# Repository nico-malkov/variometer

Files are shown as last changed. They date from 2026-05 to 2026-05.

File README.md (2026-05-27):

<b> Variometer v1.5 (hardware) v143 (software) </b>

The goal of this project is to create a miniature smart device for hobby paragliding: a variometer. The initial concept is as follows:

 <br>

<b> The current version of the project has successfully achieved its technical objectives and is being released for public access. It implements the following features: </b>

• Compact size and minimum weight of 23 grams <br>
• Power from solar cells of 170 mW at peak with consumption of 40 mW at average <br>
• IP67 rating with PTFE vented barometer membrane <br>
• Acoustic variometer with responsive Kalman filter, combining data from ms5637 barometer and icm20948 IMU <br>
• Built-in capacitive touch button <br>
• nRF52840 Cortex-M4 microcontroller unit with Bluetooth capability <br>
• Secure firmware update via Bluetooth with NRF Connect android app <br>
• Integration with XCTrack android app for sourcing barometer data <br>
• Sourcing of GPS data from ORG1410 module <br>
• Creation of txt logs <br>
• Connection to PC via USB as a mass-storage device <br>



 <br>

<b> The flaws of the current design include: </b>

• No IGC-format GPS tracking in software (to-do) <br>
• Large power consumption in GPS tracking mode: up to 60 mW <br>
• Custom manufacturing of solar cells is totally unpractical even though it is possible <br>

 <br>

<b> The project folder contains 'hardware' and 'software' subfolders: </b> <br>

1) The 'hardware' folder contains a "PCB" subfolder with the complete project in Altium Designer. To open it start with the file: <br>
variometer\hardware\PCB\v1.5 Project.PrjPcb <br>

 <br>

2) The 'hardware' folder contains a 'case' subfolder with the 3D model in Solid Works. To open it start with the file: <br>
variometer\hardware\case\v1.5 Case.SLDPRT <br>

 <br>

3) The 'software' folder contains an 'nRF5_SDK_17.1.0' subfolder with the complete project in Segger Embedded Studio. To open it start with the file: <br>
variometer\software\nRF5_SDK_17.1.0\examples\peripheral\variometer_v143\vario1d5\s140\ses\vario1d5_s140.emProject <br>

 <br>

Please contact me with any questions via email nicomalkov@yandex.com <br>

<b> Cheers! </b> <br>



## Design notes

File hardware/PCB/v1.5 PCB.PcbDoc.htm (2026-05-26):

Reporting Options

# File in Newer Format

Date | : | 15.07.2021
Time | : | 13:31:14
Filename | : | C:\Users\Engineer\YandexDisk-nicomalkov\Share\Altium\Ungravity 1.5\Ungravity 1.5 PCB.PcbDoc

Version | Warning
Release 17.0 | CAUTION - Component parameters added.
Release 17.0 | CAUTION - Supports of backdrilling

This file was generated by a later version of the software

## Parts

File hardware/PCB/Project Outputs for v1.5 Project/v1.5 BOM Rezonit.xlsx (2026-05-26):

Comment | Description | Designator | Footprint | LibRef | Quantity
10 uF |  | C1, C7, C9, C22 | 0603 | Capasistor | 4
0.01 uF |  | C2, C4 | 0402 | Capasistor | 2
4.7 uF |  | C3, C6, C8, C11, C14 | 0402 | Capasistor | 5
0.1 uF |  | C5, C10, C15, C16, C18, C19, C20, C21, C23 | 0402 | Capasistor | 9
8 pF |  | C12, C13 | 0402 | Capasistor | 2
Do not assemble (else - 8 pF) |  | C17 | 0402 | Capasistor | 1
BAS16XV2T1G |  | D1 | SOD-523 | Diode | 1
Comment |  | Designator3, Designator4, Designator5, Designator6, Designator7, Designator8 | FIDUCIAL MARK |  | 6
LiPo 150 mA*h |  | G1 | LPV551230 | Accumulator | 1
IFSC1515AHER220M01 22 uH |  | L1 | IFSC1515-AH-01 | Inductor | 1
IFSC1515AHER2R2M01 2.2 uH |  | L2 | IFSC1515-AH-01 | Inductor | 1
Test сonnector pads |  | P1 | TEST CONNECTOR | Test сonnector pads | 1
U-E-M5SS-W-0 |  | P2 | U-E-M5SS-W-0 | micro-USB port | 1
SMAT-13S |  | PZT1 | SMAT-13-MOUNT BY WIRE | Piezo transducer | 1
250 R |  | R1 | 0402 | Resistor | 1
3.9 M |  | R2, R10, R11, R17 | 0402 | Resistor | 4
5.49 M |  | R3, R9 | 0402 | Resistor | 2
3.65 M |  | R4 | 0402 | Resistor | 1
6 M |  | R5 | 0402 | Resistor | 1
1 M |  | R6 | 0402 | Resistor | 1
10 M |  | R7 | 0402 | Resistor | 1
4.87 M |  | R8 | 0402 | Resistor | 1
500 R |  | R12, R18 | 0402 | Resistor | 2
6.6 K |  | R13, R14, R15, R19, R20, R21, R24 | 0402 | Resistor | 7
5.76 M |  | R16 | 0402 | Resistor | 1
27 R |  | R22, R23 | 0402 | Resistor | 2
B3U-1000P |  | SW1 | B3U-1000P | Tact switch | 1
BQ25504 |  | U1 | BQ25504 | BQ25504 | 1
TPS62740DSSR |  | U2 | TPS62740 | TPS62740 | 1
MCP73832-2ATI/MC |  | U3 | MCP73832-2ATI/MC | MCP73832-2ATI/MC | 1
MDBT50Q-P1MV2 (NRF52840) |  | U4 | MDBT50Q-P1M | MDBT50Q | 1
TLV9002SIRUGR |  | U5 | X2QFN | TLV9002S | 1
MX25R6435FZAIL0 |  | U6 | MX25R6435F-ZA | MX25R6435F-ZA | 1
TTP223-BA6 |  | U7 | SOT23-6 | TTP223-BA6 | 1
ICM20948 |  | U8 | ICM20948 | ICM20948 | 1
MS5637 |  | U9 | MS5637-02BA03 | MS5637-02BA03 | 1
ORG1410-PM01 |  | U10 | ORG1410-PM01 | ORG1410-PM01 | 1
PESD5Z5.0 |  | VD1, VD2, VD3, VD4 | SOD-523 | Stabilitron | 4
PESD5Z7.0 |  | VD5 | SOD-523 | Stabilitron | 1
9HT11-32.768KDZY-T |  | XC1 | 9HT11 | Qartz | 1

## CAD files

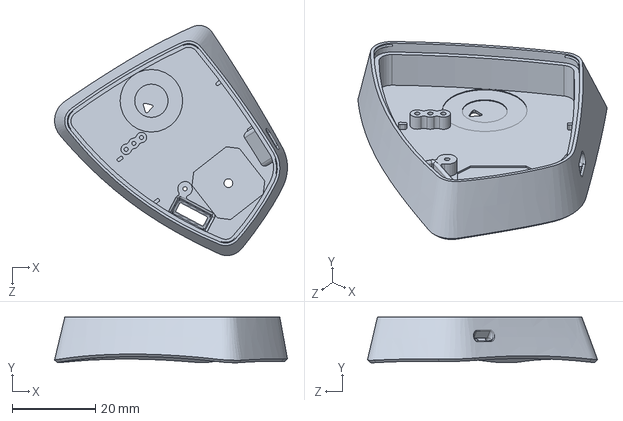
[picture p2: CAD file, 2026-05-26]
hardware/case/v1.5 Case.SLDPRT
55.8 x 10.9 x 55.2 mm

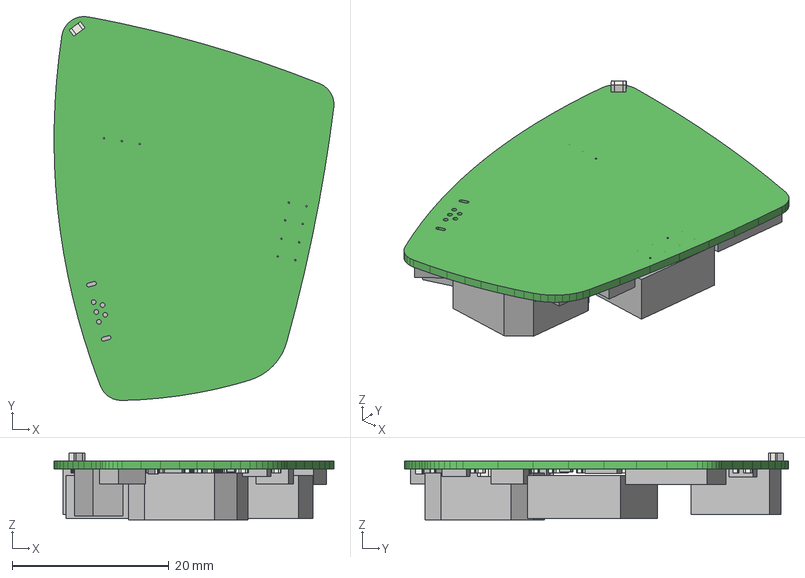
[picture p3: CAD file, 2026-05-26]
hardware/PCB/v1.5 PCB.step
35.7 x 48.9 x 8.50 mm
Board
Extruded x 173

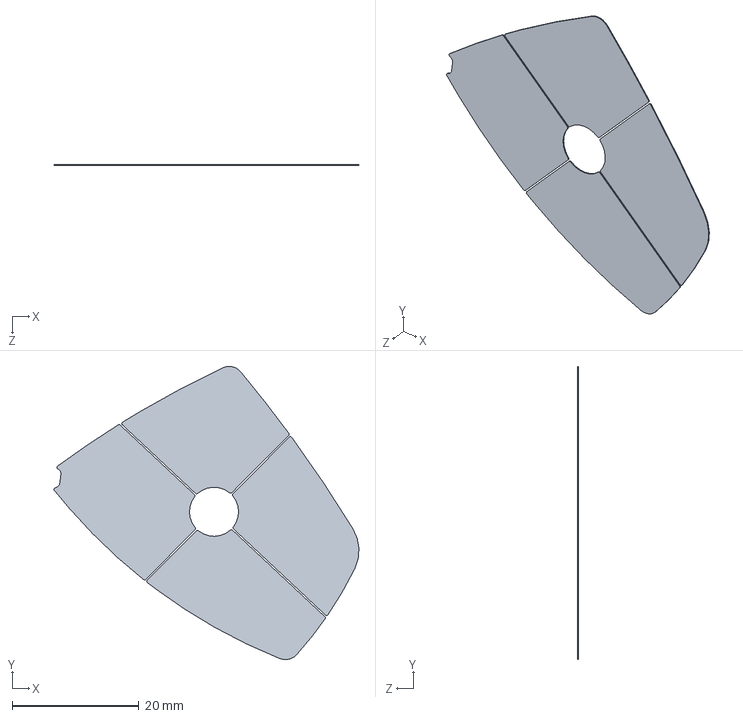
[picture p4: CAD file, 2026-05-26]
hardware/case/Solar Cells.SLDPRT
48.1 x 46.3 x 0.16 mm

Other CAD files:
hardware/case/v1.5 Case.STL

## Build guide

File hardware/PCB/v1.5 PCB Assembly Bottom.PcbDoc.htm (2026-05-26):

Reporting Options

# File in Newer Format

Date | : | 28.06.2021
Time | : | 20:50:02
Filename | : | C:\Users\Engineer\YandexDisk-nicomalkov\Share\Altium\Ungravity 1.5\Ungravity 1.5 PCB Assembly Bottom.PcbDoc

Version | Warning
Release 17.0 | CAUTION - Component parameters added.
Release 17.0 | CAUTION - Supports of backdrilling

This file was generated by a later version of the software

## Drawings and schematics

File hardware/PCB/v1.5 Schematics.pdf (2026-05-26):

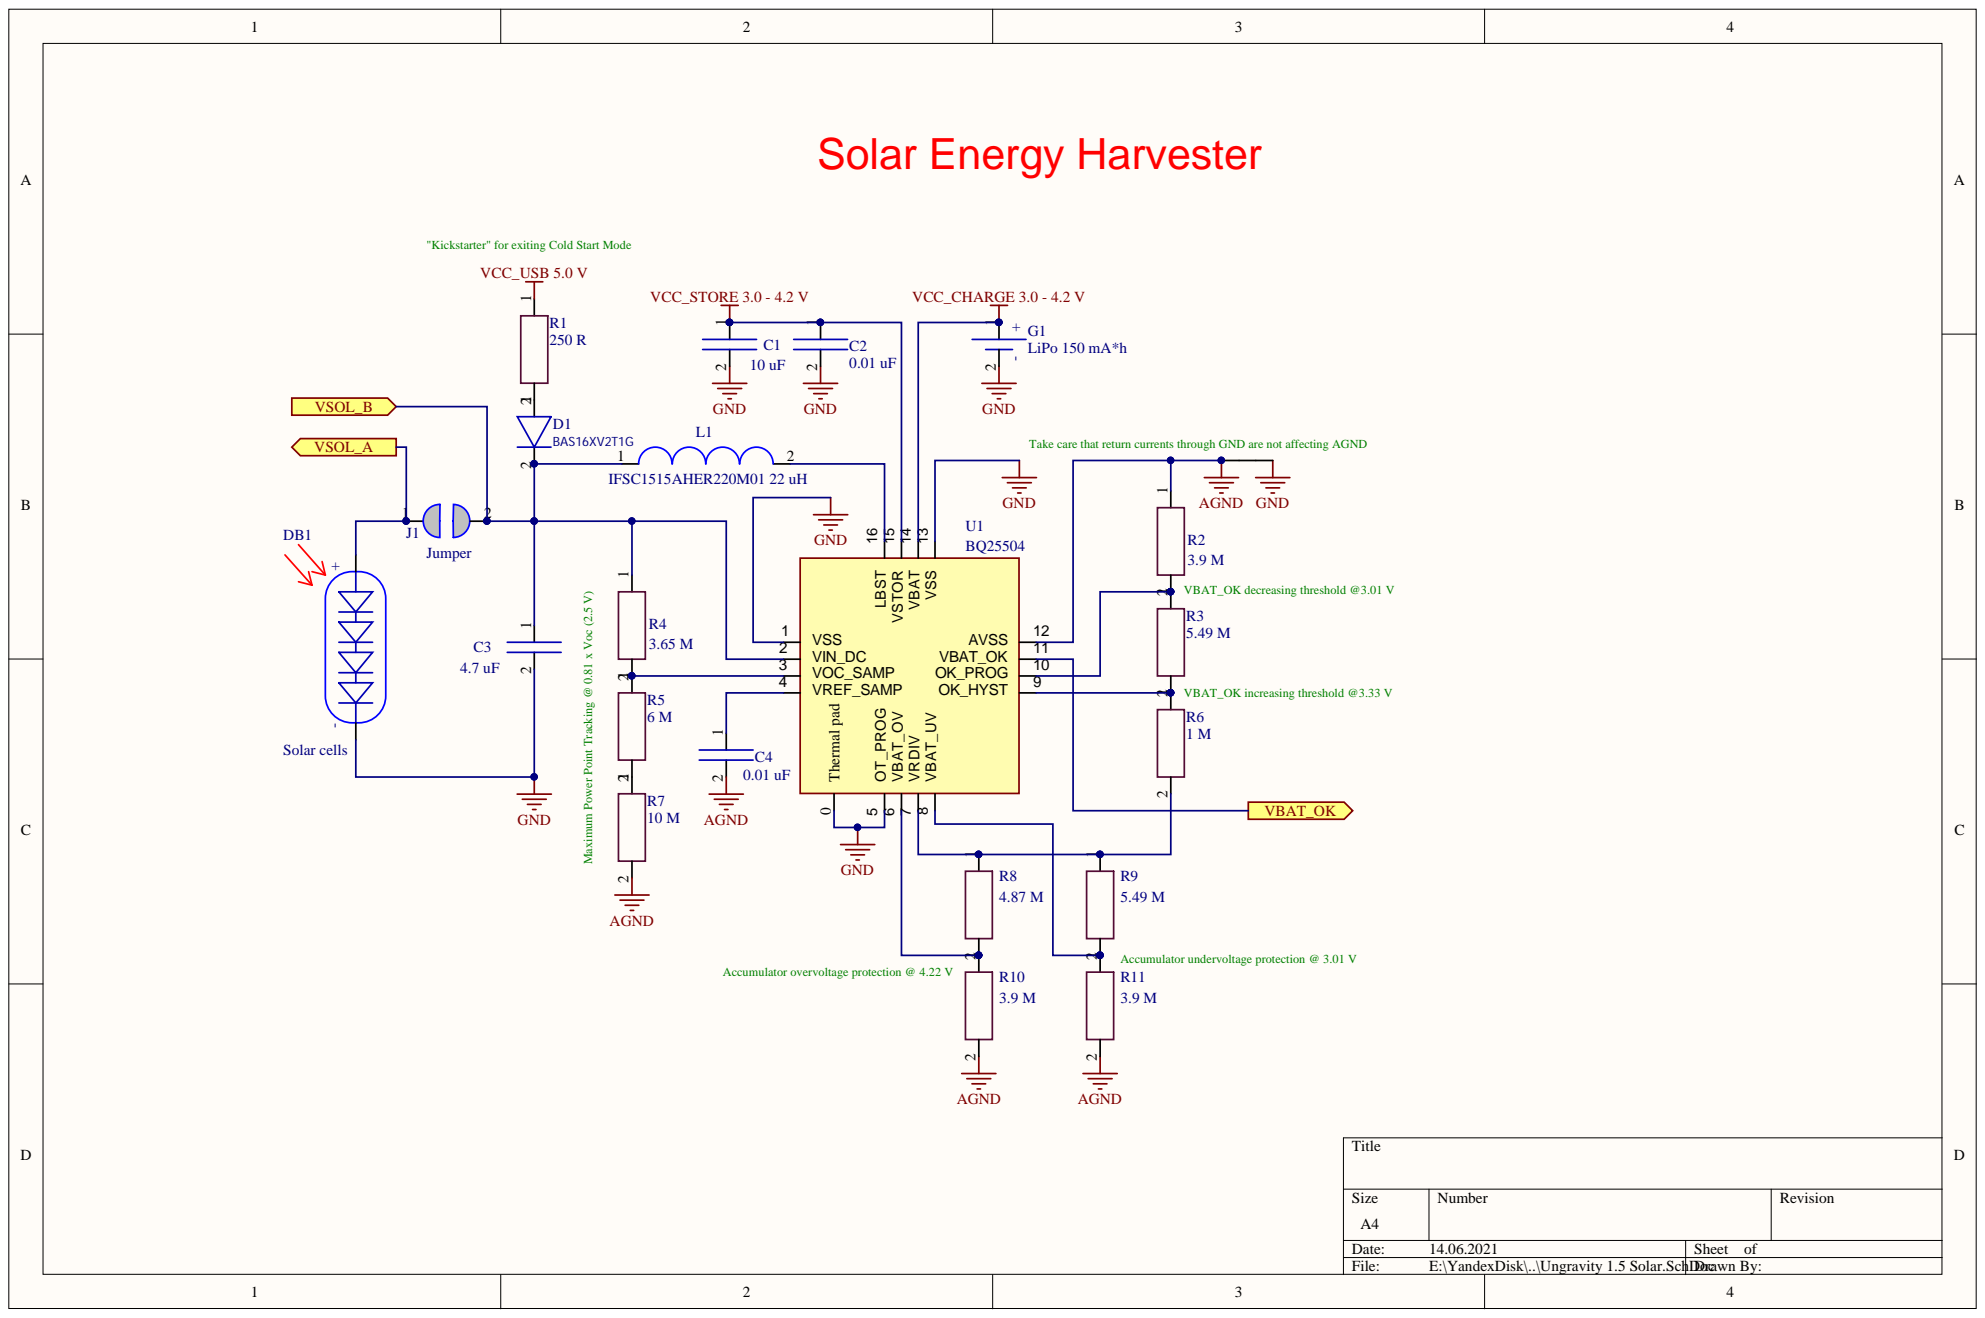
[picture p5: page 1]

Take care that return currents thro

VSS 13 VBAT 14 VSTOR 15 LBST 16

Maximum Power Point Tracking @ 0.81 x Voc (2.5 V)

2 | V I N V O V | 1 1
3 | | 1 0

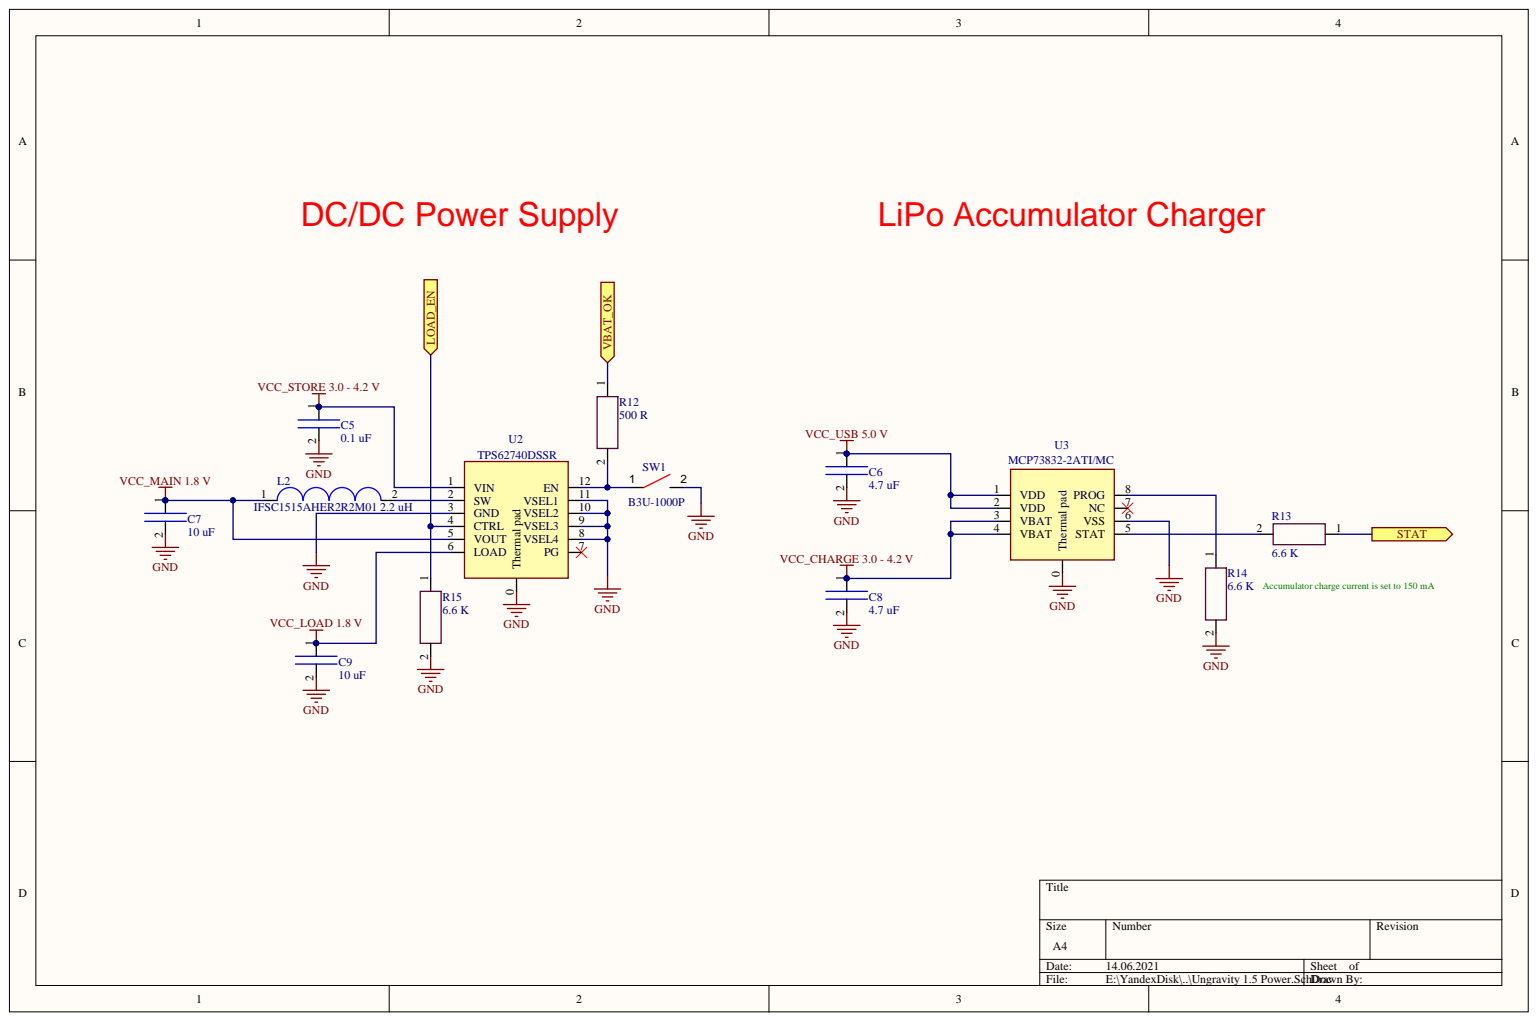
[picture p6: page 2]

ulator charge current is set to 1

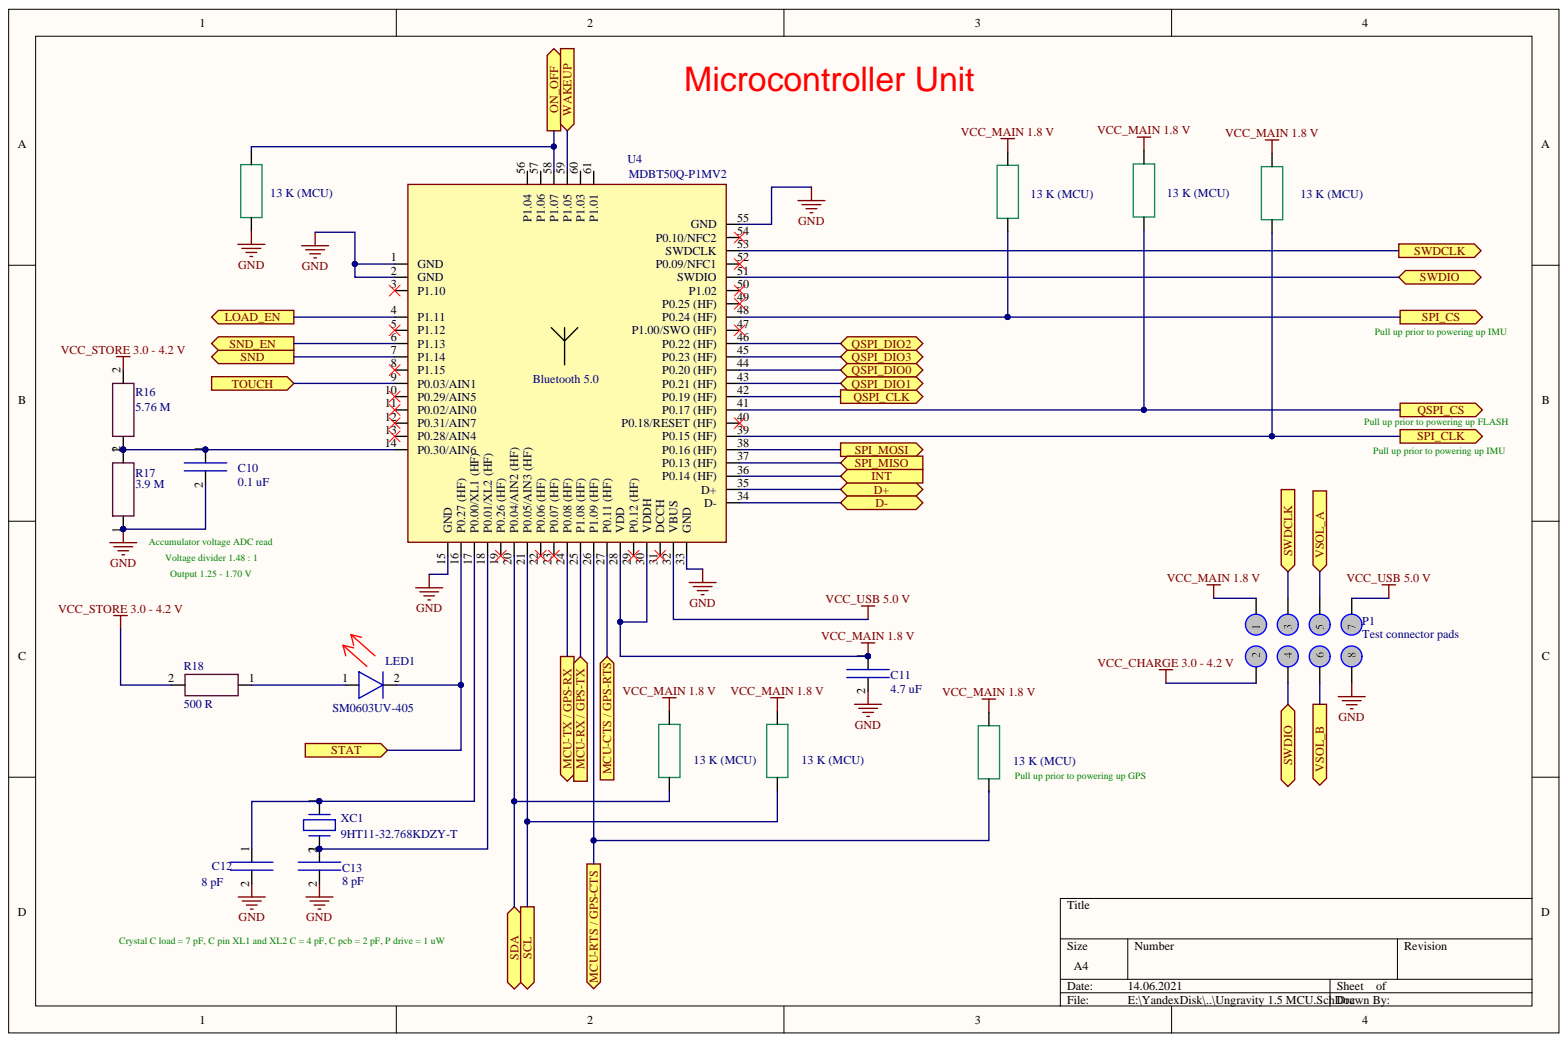
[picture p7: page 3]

Crystal C load = 7 pF, C pin XL

2 C = 4 pF, C pcb = 2 pF, P drive = 1 u

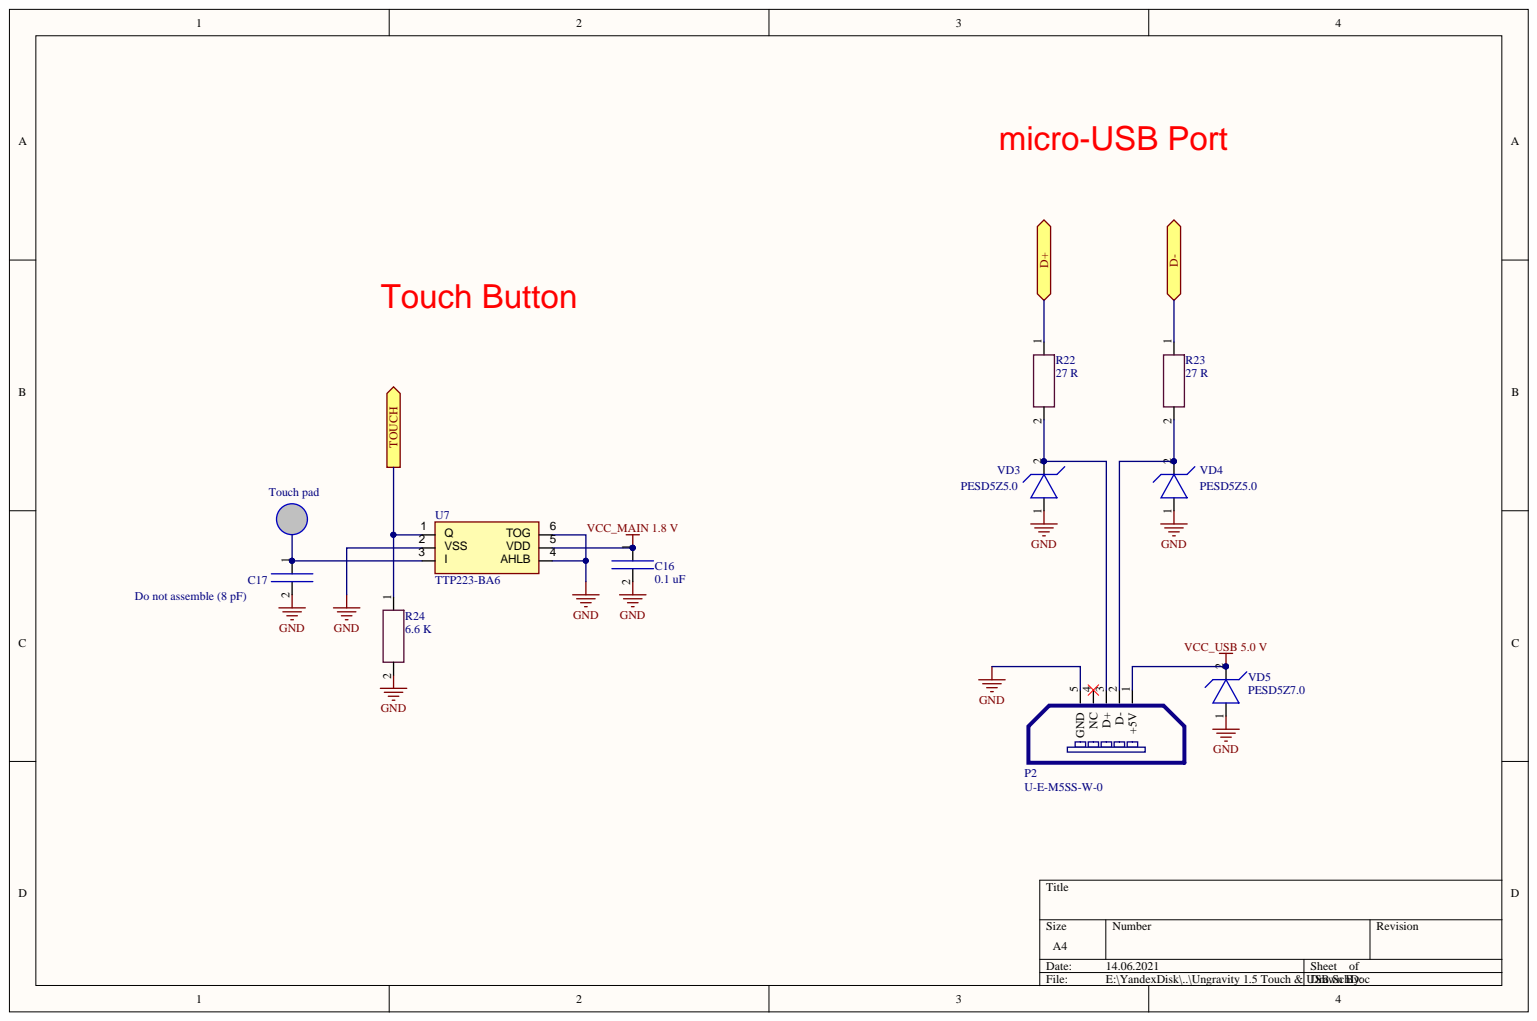
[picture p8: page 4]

Do not assemble (8 pF)

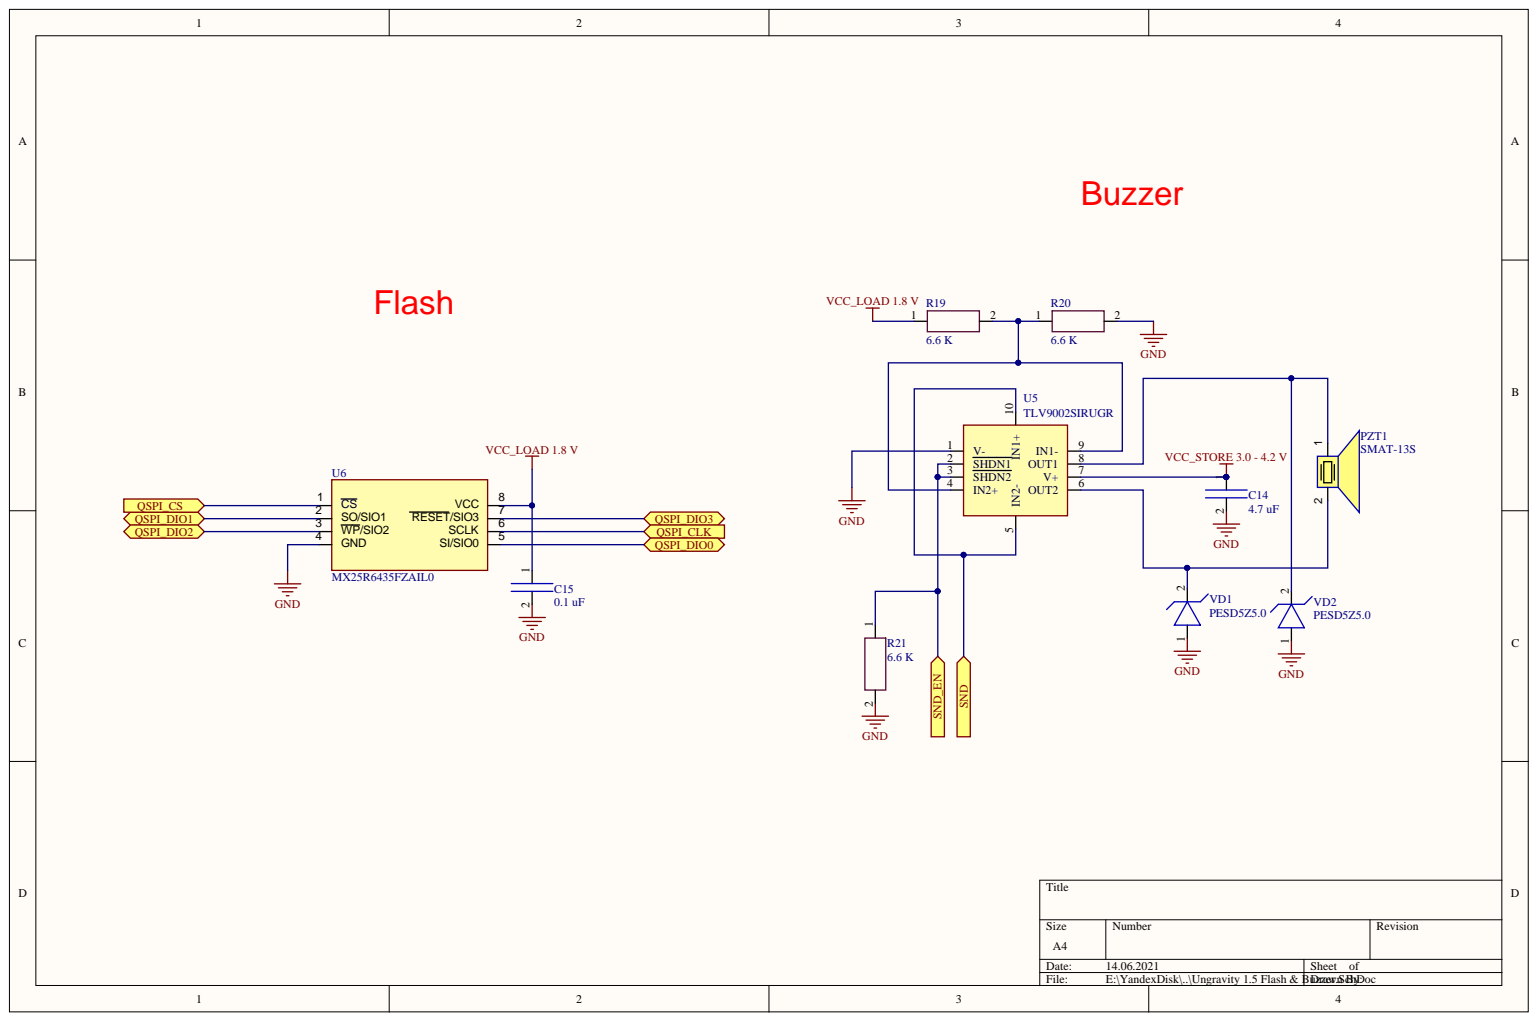
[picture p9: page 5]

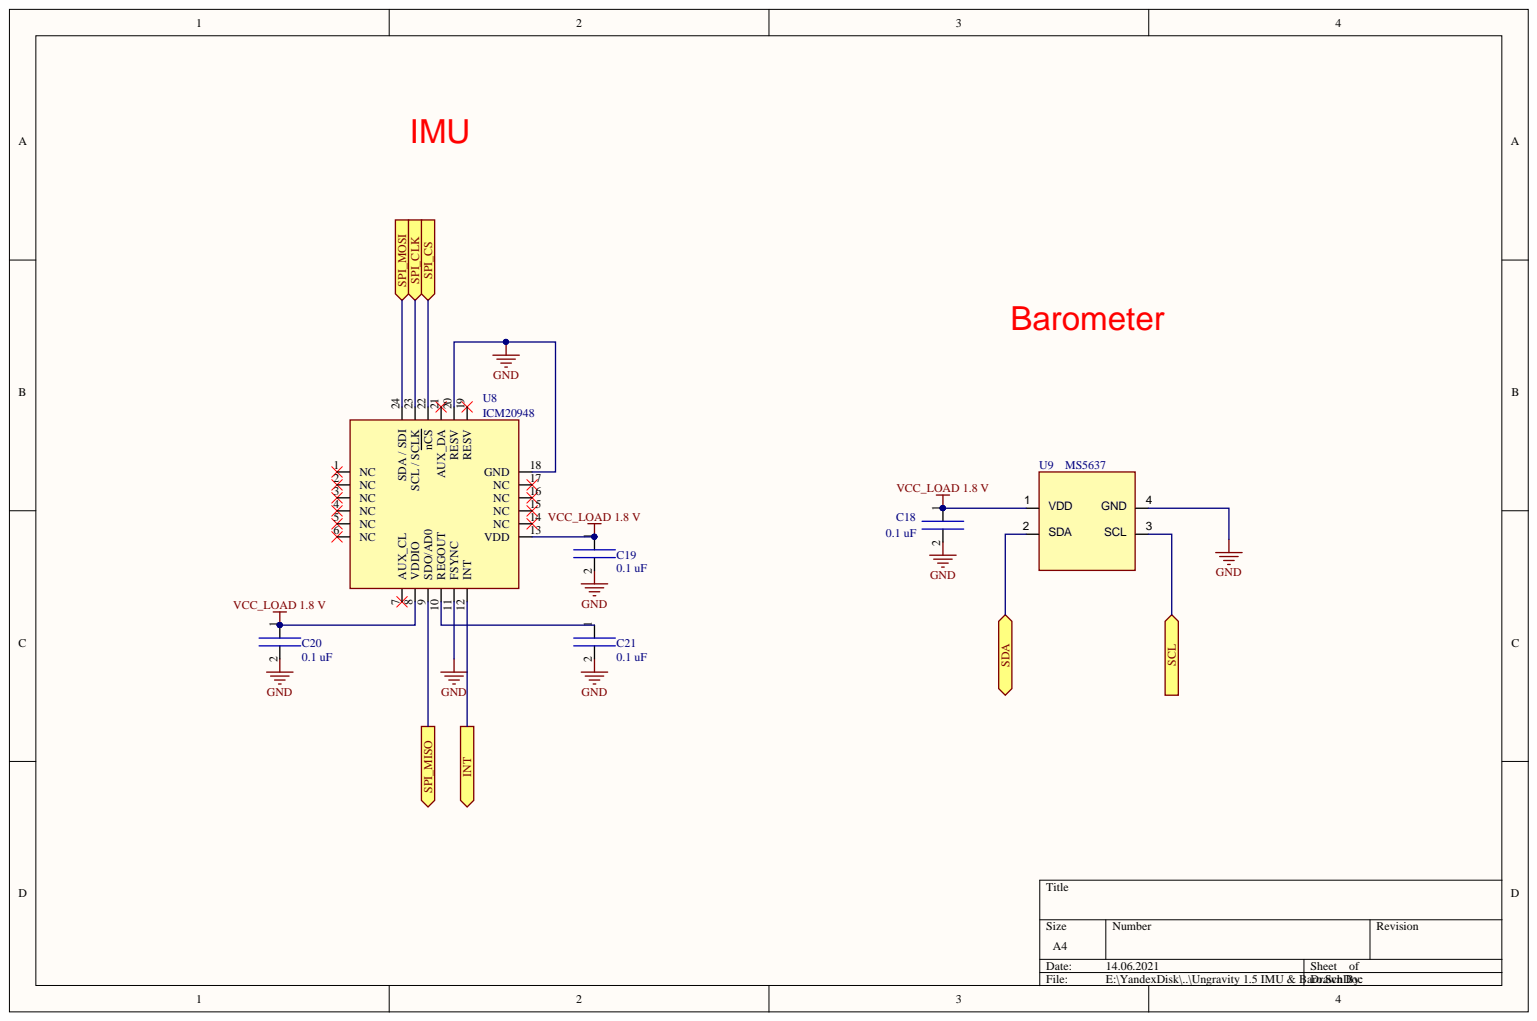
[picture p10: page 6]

RESV 19 RESV 20 AUX_DA 21 nCS 22 SCL / SCLK 23 SDA / SDI 24

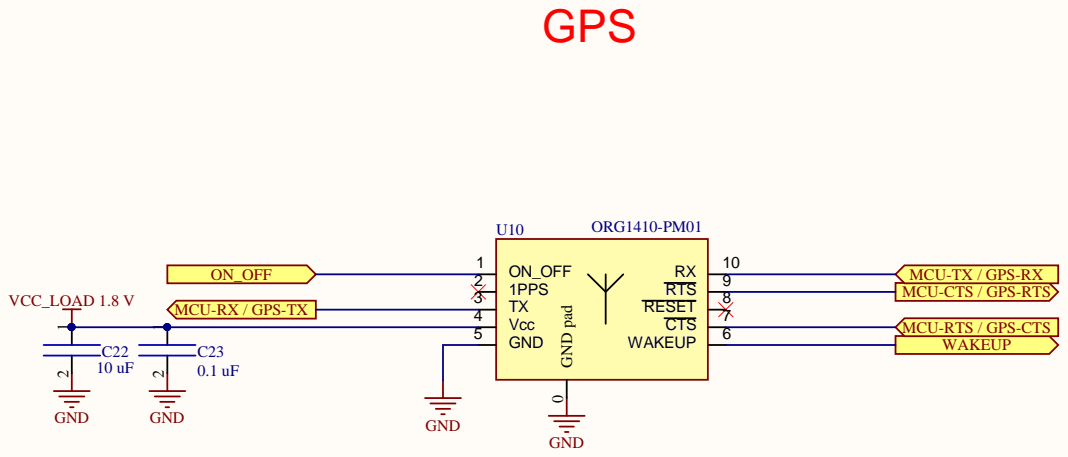
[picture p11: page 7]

MCU-TX / GPS-RX
MCU-CTS / GPS-RTS

MCU-RX / GPS-TX

MCU-RTS / GPS-CTS
WAKEUP

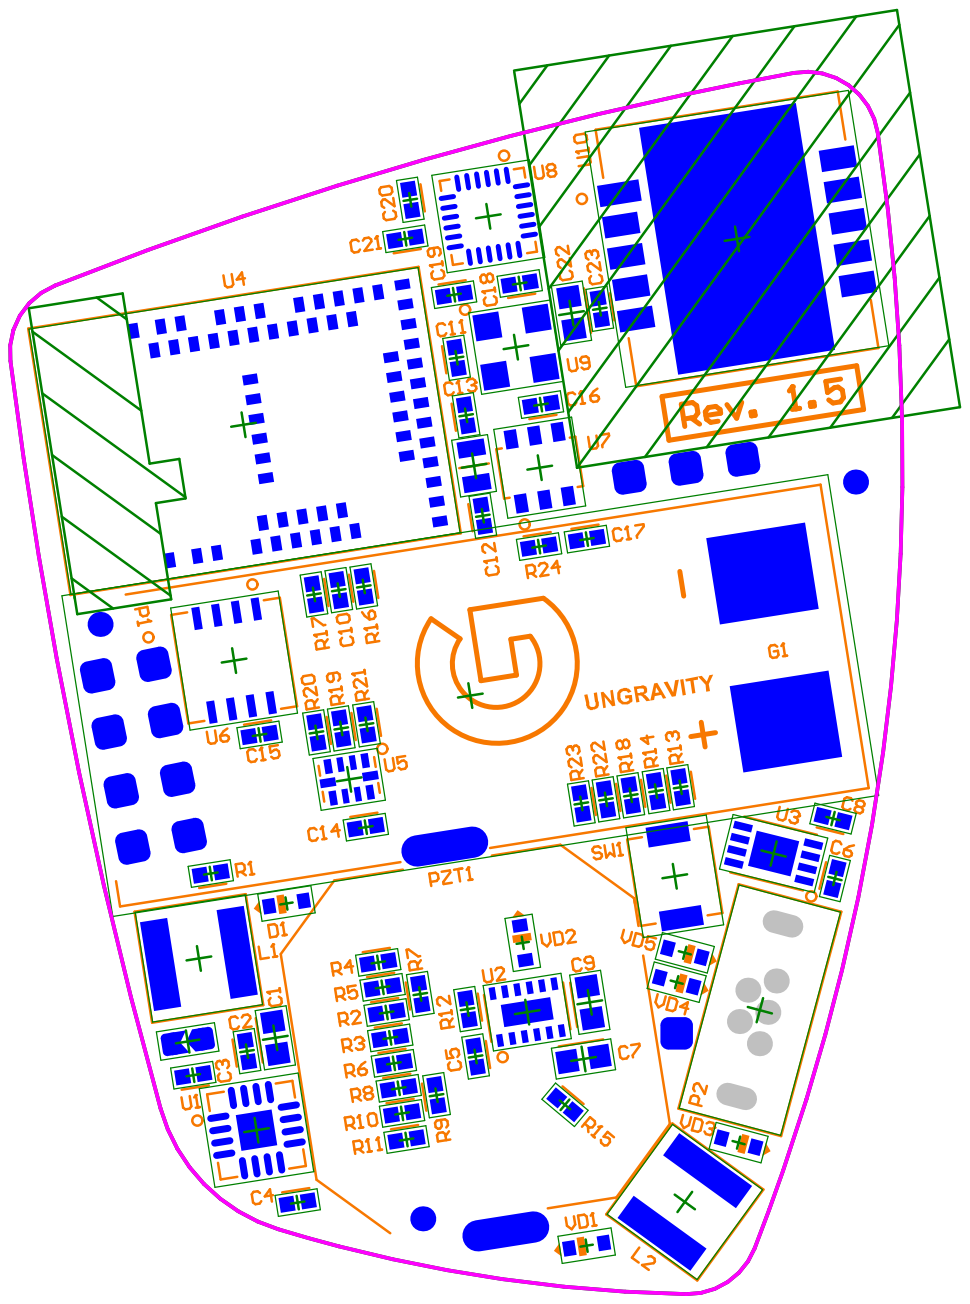
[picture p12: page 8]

Comment | Description | Designator | Footprint | LibRef | Quantity
10 uF | | C1, C7, C9, C22 | 0603 | Capasistor | 4
0.01 uF | | C2, C4 | 0402 | Capasistor | 2
4.7 uF | | C3, C6, C8, C11, C14 | 0402 | Capasistor | 5
0.1 uF | | C5, C10, C15, C16, C18, C19, C20, C21, C23 | 0402 | Capasistor | 9
8 pF | | C12, C13 | 0402 | Capasistor | 2
BAS16XV2T1G | | D1 | SOD-523 | Diode | 1
IFSC1515AHER220M 01 22 uH | | L1 | IFSC1515-AH-01 | Inductor | 1
IFSC1515AHER2R2M 01 2.2 uH | | L2 | IFSC1515-AH-01 | Inductor | 1
250 R | | R1 | 0402 | Resistor | 1
3.9 M | | R2, R10, R11, R17 | 0402 | Resistor | 4
5.49 M | | R3, R9 | 0402 | Resistor | 2
3.65 M | | R4 | 0402 | Resistor | 1
6 M | | R5 | 0402 | Resistor | 1
1 M | | R6 | 0402 | Resistor | 1
10 M | | R7 | 0402 | Resistor | 1
4.87 M | | R8 | 0402 | Resistor | 1
500 R | | R12, R18 | 0402 | Resistor | 2
6.6 K | | R13, R14, R15, R19, R20, R21, R24 | 0402 | Resistor | 7
5.76 M | | R16 | 0402 | Resistor | 1
27 R | | R22, R23 | 0402 | Resistor | 2
B3U-1000P | | SW1 | B3U-1000P | Tact switch | 1
BQ25504 | | U1 | BQ25504 | BQ25504 | 1
TPS62740DSSR | | U2 | TPS62740 | TPS62740 | 1
MCP73832-2ATI/MC | | U3 | MCP73832-2ATI/MC | MCP73832-2ATI/MC | 1
MDBT50Q-P1MV2 | | U4 | MDBT50Q-P1M | MDBT50Q | 1
TLV9002SIRUGR | | U5 | X2QFN | TLV9002S | 1
MX25R6435FZAIL0 | | U6 | MX25R6435F-ZA | MX25R6435F-ZA | 1
TTP223-BA6 | | U7 | SOT23-6 | TTP223-BA6 | 1
ICM20948 | | U8 | ICM20948 | ICM20948 | 1
MS5637 | | U9 | MS5637-02BA03 | MS5637-02BA03 | 1
ORG1410-PM01 | | U10 | ORG1410-PM01 | ORG1410-PM01 | 1
PESD5Z5.0 | | VD1, VD2, VD3, VD4 | SOD-523 | Stabilitron | 4
PESD5Z7.0 | | VD5 | SOD-523 | Stabilitron | 1
9HT11-32.768KDZY-T | | XC1 | 9HT11 | Qartz | 1

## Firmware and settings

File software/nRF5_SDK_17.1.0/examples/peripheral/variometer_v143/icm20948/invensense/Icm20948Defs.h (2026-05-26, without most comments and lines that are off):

#define _INV_ICM20948_DEFINES_H_
#include <string.h>
#include <stdlib.h>
#include "Icm20948Dmp3Driver.h"
#ifdef __cplusplus
extern "C" {
#endif
#define HW_AK8963 0x20
#define HW_AK8975 0x21
#define HW_AK8972 0x22
#define HW_AK09911 0x23
#define HW_AK09912 0x24
#define HW_AK09916 0x25
#define HW_ICM20648 0x01
#define HW_ICM20948 0x02
#define USE_ICM20948 1
#if defined USE_ICM20648
#define IMU_CHIP  HW_ICM20648
#endif
#if defined USE_ICM20948
#define IMU_CHIP  HW_ICM20948
#endif
#if !defined(IMU_CHIP)
    #error "IMU_CHIP is not defined"
#elif IMU_CHIP != HW_ICM20648 \
        && IMU_CHIP != HW_ICM20948
    #error "Unknown value for IMU_CHIP"
#endif
#define DMP_LOAD_START 0x90
#define MPU_SUCCESS (0)
#define MPU_COMPASS_NOT_FOUND (int)0x00ABCDEF
#define MSEC_PER_SEC 1000
#define NSEC_PER_MSEC 1000000
#define NSEC_PER_SEC NSEC_PER_MSEC * MSEC_PER_SEC
#define FIFO_DIVIDER 19
#define REG_BANK_0 0x00
#define REG_BANK_1 0x01
#define DIAMOND_I2C_ADDRESS     0x68
#define BANK_0                  (0 << 7)
#define BANK_1                  (1 << 7)
#define BANK_2                  (2 << 7)
#define BANK_3                  (3 << 7)
#define REG_WHO_AM_I            (BANK_0 | 0x00)
#define REG_LPF                 (BANK_0 | 0x01)
#define REG_USER_CTRL           (BANK_0 | 0x03)
#define BIT_DMP_EN                      0x80
#define BIT_FIFO_EN                     0x40
#define BIT_I2C_MST_EN                  0x20
#define BIT_I2C_IF_DIS                  0x10
#define BIT_DMP_RST                     0x08
#define BIT_DIAMOND_DMP_RST			    0x04
#define REG_LP_CONFIG           (BANK_0 | 0x05)
#define BIT_I2C_MST_CYCLE               0x40
#define BIT_ACCEL_CYCLE                 0x20
#define BIT_GYRO_CYCLE                  0x10
#define REG_PWR_MGMT_1          (BANK_0 | 0x06)
#define BIT_H_RESET                     0x80
#define BIT_SLEEP                       0x40
#define BIT_LP_EN                       0x20
#define BIT_CLK_PLL                     0x01
#define REG_PWR_MGMT_2          (BANK_0 | 0x07)
#define BIT_PWR_PRESSURE_STBY           0x40
#define BIT_PWR_ACCEL_STBY              0x38
#define BIT_PWR_GYRO_STBY               0x07
#define BIT_PWR_ALL_OFF                 0x7f
#define REG_INT_PIN_CFG         (BANK_0 | 0x0F)
#define BIT_INT_LATCH_EN                0x20
#define BIT_BYPASS_EN                   0x02
#define REG_INT_ENABLE          (BANK_0 | 0x10)
#define BIT_DMP_INT_EN                  0x02
#define REG_INT_ENABLE_1        (BANK_0 | 0x11)
#define BIT_DATA_RDY_3_EN               0x08
#define BIT_DATA_RDY_2_EN               0x04
#define BIT_DATA_RDY_1_EN               0x02
#define BIT_DATA_RDY_0_EN               0x01
#define REG_INT_ENABLE_2        (BANK_0 | 0x12)
#define BIT_FIFO_OVERFLOW_EN_0          0x1
#define REG_INT_ENABLE_3        (BANK_0 | 0x13)
#define REG_DMP_INT_STATUS      (BANK_0 | 0x18)
#define BIT_WAKE_ON_MOTION_INT          0x08
#define BIT_MSG_DMP_INT                 0x0002
#define BIT_MSG_DMP_INT_0               0x0100  // CI Command
#define BIT_MSG_DMP_INT_2               0x0200  // CIM Command - SMD
#define BIT_MSG_DMP_INT_3               0x0400  // CIM Command - Pedometer
#define BIT_MSG_DMP_INT_4               0x1000  // CIM Command - Pedometer binning
#define BIT_MSG_DMP_INT_5               0x2000  // CIM Command - Bring To See Gesture
#define BIT_MSG_DMP_INT_6               0x4000  // CIM Command - Look To See Gesture
#define REG_INT_STATUS          (BANK_0 | 0x19)
#define BIT_DMP_INT                     0x02
#define REG_INT_STATUS_1        (BANK_0 | 0x1A)
#define REG_INT_STATUS_2        (BANK_0 | 0x1B)
#define REG_SINGLE_FIFO_PRIORITY_SEL        (BANK_0 | 0x26)
#define REG_GYRO_XOUT_H_SH      (BANK_0 | 0x33)
#define REG_TEMPERATURE         (BANK_0 | 0x39)
#define REG_TEMP_CONFIG         (BANK_0 | 0x53)
#define REG_EXT_SLV_SENS_DATA_00 (BANK_0 | 0x3B)
#define REG_EXT_SLV_SENS_DATA_08 (BANK_0 | 0x43)
#define REG_EXT_SLV_SENS_DATA_09 (BANK_0 | 0x44)
#define REG_EXT_SLV_SENS_DATA_10 (BANK_0 | 0x45)
#define REG_FIFO_EN             (BANK_0 | 0x66)
#define BIT_SLV_0_FIFO_EN               0x01
#define REG_FIFO_EN_2           (BANK_0 | 0x67)
#define BIT_PRS_FIFO_EN                 0x20
#define BIT_ACCEL_FIFO_EN               0x10
#define BITS_GYRO_FIFO_EN               0x0E
#define REG_FIFO_RST            (BANK_0 | 0x68)
#define REG_FIFO_COUNT_H        (BANK_0 | 0x70)
#define REG_FIFO_COUNT_L        (BANK_0 | 0x71)
#define REG_FIFO_R_W            (BANK_0 | 0x72)
#define REG_HW_FIX_DISABLE      (BANK_0 | 0x75)
#define REG_FIFO_CFG            (BANK_0 | 0x76)
#define BIT_MULTI_FIFO_CFG              0x01
#define BIT_SINGLE_FIFO_CFG             0x00
#define REG_ACCEL_XOUT_H_SH     (BANK_0 | 0x2D)
#define REG_ACCEL_XOUT_L_SH     (BANK_0 | 0x2E)
#define REG_ACCEL_YOUT_H_SH     (BANK_0 | 0x2F)
#define REG_ACCEL_YOUT_L_SH     (BANK_0 | 0x30)
#define REG_ACCEL_ZOUT_H_SH     (BANK_0 | 0x31)
#define REG_ACCEL_ZOUT_L_SH     (BANK_0 | 0x32)
#define REG_MEM_START_ADDR      (BANK_0 | 0x7C)
#define REG_MEM_R_W             (BANK_0 | 0x7D)
#define REG_MEM_BANK_SEL        (BANK_0 | 0x7E)
#define REG_TIMEBASE_CORRECTION_PLL   (BANK_1 | 0x28)
#define REG_TIMEBASE_CORRECTION_RCOSC (BANK_1 | 0x29)
#define REG_SELF_TEST1                (BANK_1 | 0x02)
#define REG_SELF_TEST2                (BANK_1 | 0x03)
#define REG_SELF_TEST3                (BANK_1 | 0x04)
#define REG_SELF_TEST4                (BANK_1 | 0x0E)
#define REG_SELF_TEST5                (BANK_1 | 0x0F)
#define REG_SELF_TEST6                (BANK_1 | 0x10)
#define REG_GYRO_SMPLRT_DIV     (BANK_2 | 0x00)
#define REG_GYRO_CONFIG_1       (BANK_2 | 0x01)
#define SHIFT_GYRO_FS_SEL               1
#define SHIFT_GYRO_DLPCFG               3
#define REG_GYRO_CONFIG_2       (BANK_2 | 0x02)
#define BIT_GYRO_CTEN                   0x38
#define REG_ACCEL_SMPLRT_DIV_1  (BANK_2 | 0x10)
#define REG_ACCEL_SMPLRT_DIV_2  (BANK_2 | 0x11)
#define REG_ACCEL_CONFIG        (BANK_2 | 0x14)
#define SHIFT_ACCEL_FS                  1
#define REG_ACCEL_CONFIG_2      (BANK_2 | 0x15)
#define BIT_ACCEL_CTEN                  0x1C
#define REG_PRS_ODR_CONFIG      (BANK_2 | 0x20)
#define REG_PRGM_START_ADDRH    (BANK_2 | 0x50)
#define REG_MOD_CTRL_USR        (BANK_2 | 0x54)
#define BIT_ODR_SYNC                    0x7
#define REG_I2C_MST_ODR_CONFIG  (BANK_3 | 0x0)
#define REG_I2C_MST_CTRL        (BANK_3 | 0x01)
#define BIT_I2C_MST_P_NSR               0x10
#define REG_I2C_MST_DELAY_CTRL  (BANK_3 | 0x02)
#define BIT_SLV0_DLY_EN                 0x01
#define BIT_SLV1_DLY_EN                 0x02
#define BIT_SLV2_DLY_EN                 0x04
#define BIT_SLV3_DLY_EN                 0x08
#define REG_I2C_SLV0_ADDR       (BANK_3 | 0x03)
#define REG_I2C_SLV0_REG        (BANK_3 | 0x04)
#define REG_I2C_SLV0_CTRL       (BANK_3 | 0x05)
#define REG_I2C_SLV0_DO         (BANK_3 | 0x06)
#define REG_I2C_SLV1_ADDR       (BANK_3 | 0x07)
#define REG_I2C_SLV1_REG        (BANK_3 | 0x08)
#define REG_I2C_SLV1_CTRL       (BANK_3 | 0x09)
#define REG_I2C_SLV1_DO         (BANK_3 | 0x0A)
#define REG_I2C_SLV2_ADDR       (BANK_3 | 0x0B)
#define REG_I2C_SLV2_REG        (BANK_3 | 0x0C)
#define REG_I2C_SLV2_CTRL       (BANK_3 | 0x0D)
#define REG_I2C_SLV2_DO         (BANK_3 | 0x0E)
#define REG_I2C_SLV3_ADDR       (BANK_3 | 0x0F)
#define REG_I2C_SLV3_REG        (BANK_3 | 0x10)
#define REG_I2C_SLV3_CTRL       (BANK_3 | 0x11)
#define REG_I2C_SLV3_DO         (BANK_3 | 0x12)
#define REG_I2C_SLV4_CTRL       (BANK_3 | 0x15)
#define INV_MPU_BIT_SLV_EN      0x80
#define INV_MPU_BIT_BYTE_SW     0x40
#define INV_MPU_BIT_REG_DIS     0x20
#define INV_MPU_BIT_GRP         0x10
#define INV_MPU_BIT_I2C_READ    0x80
#define REG_BANK_SEL            0x7F
#define BYTES_PER_SENSOR         6
#define FIFO_COUNT_BYTE          2
#define HARDWARE_FIFO_SIZE       1024
#define FIFO_SIZE                (HARDWARE_FIFO_SIZE * 7 / 8)
#define POWER_UP_TIME            100
#define REG_UP_TIME_USEC         100
#define DMP_RESET_TIME           20
#define GYRO_ENGINE_UP_TIME      50
#define MPU_MEM_BANK_SIZE        256
#define IIO_BUFFER_BYTES         8
#define HEADERED_NORMAL_BYTES    8
#define HEADERED_Q_BYTES         16
#define LEFT_OVER_BYTES          128
#define BASE_SAMPLE_RATE         1125
#ifdef FREQ_225
#define MPU_DEFAULT_DMP_FREQ     225
#define PEDOMETER_FREQ           (MPU_DEFAULT_DMP_FREQ >> 2)
#define DEFAULT_ACCEL_GAIN       (33554432L * 5 / 11)
#else
#define MPU_DEFAULT_DMP_FREQ     102
#define PEDOMETER_FREQ           (MPU_DEFAULT_DMP_FREQ >> 1)
#define DEFAULT_ACCEL_GAIN       33554432L
#endif
#define PED_ACCEL_GAIN           67108864L
#define ALPHA_FILL_PED           858993459
#define A_FILL_PED               214748365
#define MIN_MST_ODR_CONFIG       4
#define THREE_AXES               3
#define NINE_ELEM                (THREE_AXES * THREE_AXES)
#define MPU_TEMP_SHIFT           16
#define SOFT_IRON_MATRIX_SIZE    (4 * 9)
#define DMP_DIVIDER              (BASE_SAMPLE_RATE / MPU_DEFAULT_DMP_FREQ)
#define MAX_5_BIT_VALUE          0x1F
#define BAD_COMPASS_DATA         0x7FFF
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

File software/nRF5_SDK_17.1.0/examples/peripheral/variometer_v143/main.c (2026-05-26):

/**
 * Copyright (c) 2017 - 2022, Nordic Semiconductor ASA
 *
 * All rights reserved.
 *
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
 * 3. Neither the name of Nordic Semiconductor ASA nor the names of its
 *    contributors may be used to endorse or promote products derived from this
 *    software without specific prior written permission.
 *
 * 4. This software, with or without modification, must only be used with a
 *    Nordic Semiconductor ASA integrated circuit.
 *
 * 5. Any software provided in binary form under this license must not be reverse
 *    engineered, decompiled, modified and/or disassembled.
 *
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
 */

#include <inttypes.h>
#include <math.h>
#include <stdbool.h>
#include <stddef.h>
#include <stdint.h>
#include <stdio.h>
#include <stdlib.h>
#include <string.h>

#include <nrfx.h> //

#include "app_button.h"
#include "app_error.h"
#include "app_timer.h"
#include "app_uart.h"
#include "app_usbd.h"
#include "app_usbd_core.h"
#include "app_usbd_msc.h"
#include "app_usbd_string_desc.h"
#include "app_util_platform.h"
#include "ble.h"
#include "ble_advdata.h"
#include "ble_advertising.h"
#include "ble_conn_params.h"
#include "ble_conn_state.h"
// #include "ble_cus.h" //
#include "ble_dfu.h"
#include "ble_hci.h"
#include "ble_nus.h"
#include "ble_srv_common.h"
#include "boards.h"
#include "bsp.h"
#include "bsp_btn_ble.h"
#include "diskio_blkdev.h"
#include "fds.h"
#include "ff.h"
#include "nordic_common.h"
#include "nrf.h"
#include "nrf_assert.h"
#include "nrf_atomic.h"
#include "nrf_ble_gatt.h"
#include "nrf_ble_qwr.h"
#include "nrf_block_dev.h"
#include "nrf_block_dev_empty.h"
#include "nrf_block_dev_qspi.h"
#include "nrf_block_dev_ram.h"
#include "nrf_block_dev_sdc.h"
#include "nrf_bootloader_info.h"
#include "nrf_delay.h"
#include "nrf_dfu_ble_svci_bond_sharing.h"
#include "nrf_drv_clock.h"
#include "nrf_drv_gpiote.h"
#include "nrf_drv_power.h"
#include "nrf_drv_pwm.h"
#include "nrf_drv_rtc.h"
#include "nrf_drv_saadc.h" //
#include "nrf_drv_twi.h"
#include "nrf_drv_usbd.h"
#include "nrf_gpio.h"
#include "nrf_gpiote.h"
#include "nrf_libuarte_async.h"
#include "nrf_log.h"
#include "nrf_log_ctrl.h"
#include "nrf_log_default_backends.h"
#include "nrf_nvmc.h" //
#include "nrf_power.h"
#include "nrf_pwr_mgmt.h"
#include "nrf_queue.h"
#include "nrf_sdh.h"
#include "nrf_sdh_ble.h"
#include "nrf_sdh_soc.h"
#include "nrf_soc.h" //
#include "nrf_svci_async_function.h"
#include "nrf_svci_async_handler.h"
#include "peer_manager.h"
#include "peer_manager_handler.h"
#include "sensorsim.h" //
#include "timestamping.h"

#include "Device.h"
#include "DeviceIcm20948.h"
#include "Icm20948.h"
#include "Icm20948DataBaseDriver.h" // sleep function
#include "Icm20948setup.h"
#include "SensorConfig.h"
// #include "Icm20948MPUFifoControl.h"  // reset fifo    - not working

#include "battery_helper.h"
#include "myESB.h"
#include "twi_func.h"

// From ESB example
#include "app_util.h"
#include "nrf_error.h"
#include "nrf_esb.h"
#include "nrf_esb_error_codes.h"
#include "nrf_gpio.h"
#include "sdk_common.h"

//------------------------------------------------------------------------------------
// General functions part
//------------------------------------------------------------------------------------

static void log_init(void) { // function for debug logging initializing
  ret_code_t err_code = NRF_LOG_INIT(NULL);
  APP_ERROR_CHECK(err_code);

  NRF_LOG_DEFAULT_BACKENDS_INIT();
}

static void softdevice_init(void) { // function for enabling softdevice
  ret_code_t err_code = nrf_sdh_enable_request();
  APP_ERROR_CHECK(err_code);
}

static void power_management_init(void) { // function for initializing power management
  ret_code_t err_code;
  err_code = nrf_pwr_mgmt_init();
  APP_ERROR_CHECK(err_code);
}

static void idle_state_handle(void) { // function for handling the idle state (main loop) – if there is no pending log operation, then sleep until next the next event occurs
  if (NRF_LOG_PROCESS() == false) {
    nrf_pwr_mgmt_run();
  }
}

//------------------------------------------------------------------------------------
// Bluetooth part
//------------------------------------------------------------------------------------

#define APP_BLE_CONN_CFG_TAG 1                               // a tag identifying the SoftDevice BLE configuration
#define APP_BLE_OBSERVER_PRIO 3                              // application's BLE observer priority. You shouldn't need to modify this value
#define APP_ADV_INTERVAL 64                                  // the advertising interval (in units of 0.625 ms. This value corresponds to 40 ms)
#define APP_ADV_DURATION 0                                   // the advertising duration in units of 10 (millis)econds, 0 is endless
#define CONN_SUP_TIMEOUT MSEC_TO_UNITS(4000, UNIT_10_MS)     // connection supervisory timeout (4 seconds), Supervision Timeout uses 10 ms units
#define DEAD_BEEF 0xDEADBEEF                                 // value used as error code on stack dump, can be used to identify stack location on stack unwind
#define DEVICE_STRING "Vario 1.8"                  // name of the device, will be included in the advertising data
#define FIRST_CONN_PARAMS_UPDATE_DELAY APP_TIMER_TICKS(5000) // time from initiating event (connect or start of notification) to first time sd_ble_gap_conn_param_update is called (5 seconds)
#define MAX_CONN_INTERVAL MSEC_TO_UNITS(75, UNIT_1_25_MS)    // maximum acceptable connection interval (75 ms), Connection interval uses 1.25 ms units
#define MIN_CONN_INTERVAL MSEC_TO_UNITS(20, UNIT_1_25_MS)    // minimum acceptable connection interval (20 ms), Connection interval uses 1.25 ms units
#define MAX_CONN_PARAMS_UPDATE_COUNT 3
#define NEXT_CONN_PARAMS_UPDATE_DELAY APP_TIMER_TICKS(30000) // time between each call to sd_ble_gap_conn_param_update after the first call (30 seconds)
#define NUS_SERVICE_UUID_TYPE BLE_UUID_TYPE_VENDOR_BEGIN     // UUID type for the Nordic UART Service (vendor specific)
#define SEC_PARAM_BOND 1                                     // perform bonding
#define SEC_PARAM_IO_CAPABILITIES BLE_GAP_IO_CAPS_NONE       // no I/O capabilities
#define SEC_PARAM_KEYPRESS 0                                 // keypress notifications not enabled
#define SEC_PARAM_LESC 0                                     // LE Secure Connections not enabled
#define SEC_PARAM_MIN_KEY_SIZE 7                             // minimum encryption key size
#define SEC_PARAM_MITM 0                                     // Man In The Middle protection is not required
#define SEC_PARAM_MAX_KEY_SIZE 16                            //  maximum encryption key size
#define SEC_PARAM_OOB 0                                      // Out Of Band data not available
#define SLAVE_LATENCY 0                                      // slave latency

BLE_ADVERTISING_DEF(m_advertising);               // advertising module instance
BLE_NUS_DEF(m_nus, NRF_SDH_BLE_TOTAL_LINK_COUNT); // BLE NUS service instance
NRF_BLE_GATT_DEF(m_gatt);                         // GATT module instance
NRF_BLE_QWR_DEF(m_qwr);                           // context for the Queued Write module

static uint16_t m_conn_handle = BLE_CONN_HANDLE_INVALID;                           // handle of the current connection
static uint16_t m_ble_nus_max_data_len = BLE_GATT_ATT_MTU_DEFAULT - 3;             // maximum length of data (in bytes) that can be transmitted to the peer by the Nordic UART service module
static ble_uuid_t m_adv_uuids[] = {{BLE_UUID_NUS_SERVICE, NUS_SERVICE_UUID_TYPE}}; // universally unique service identifier

typedef void (*bluetooth_get_handle_t)(char S[BLE_NUS_MAX_DATA_LEN]);
static bluetooth_get_handle_t bluetooth_get_handle;

/**@brief Function for handling Queued Write Module errors.
 *
 * @details A pointer to this function will be passed to each service which may need to inform the
 *          application about an error.
 *
 * @param[in]   nrf_error   Error code containing information about what went wrong.
 */
static void nrf_qwr_error_handler(uint32_t nrf_error) {
  APP_ERROR_HANDLER(nrf_error);
}

/**@brief Handler for shutdown preparation.
 *
 * @details During shutdown procedures, this function will be called at a 1 second interval
 *          untill the function returns true. When the function returns true, it means that the
 *          app is ready to reset to DFU mode.
 *
 * @param[in]   event   Power manager event.
 *
 * @retval  True if shutdown is allowed by this power manager handler, otherwise false.
 */
static bool app_shutdown_handler(nrf_pwr_mgmt_evt_t event) {
  switch (event) {
  case NRF_PWR_MGMT_EVT_PREPARE_DFU:
    NRF_LOG_INFO("Power management wants to reset to DFU mode.");
    // YOUR_JOB: Get ready to reset into DFU mode
    //
    // If you aren't finished with any ongoing tasks, return "false" to
    // signal to the system that reset is impossible at this stage.
    //
    // Here is an example using a variable to delay resetting the device.
    //
    // if (!m_ready_for_reset)
    // {
    //      return false;
    // }
    // else
    //{
    //
    //    // Device ready to enter
    //    uint32_t err_code;
    //    err_code = sd_softdevice_disable();
    //   APP_ERROR_CHECK(err_code);
    //    err_code = app_timer_stop_all();
    //   APP_ERROR_CHECK(err_code);
    //}
    break;

  default:
    // YOUR_JOB: Implement any of the other events available from the power management module:
    //      -NRF_PWR_MGMT_EVT_PREPARE_SYSOFF
    //      -NRF_PWR_MGMT_EVT_PREPARE_WAKEUP
    //      -NRF_PWR_MGMT_EVT_PREPARE_RESET
    return true;
  }

  NRF_LOG_INFO("Power management allowed to reset to DFU mode.");
  return true;
}

NRF_PWR_MGMT_HANDLER_REGISTER(app_shutdown_handler, 0);

static void buttonless_dfu_sdh_state_observer(nrf_sdh_state_evt_t state, void *p_context) {
  if (state == NRF_SDH_EVT_STATE_DISABLED) {
    nrf_power_gpregret2_set(BOOTLOADER_DFU_SKIP_CRC);         // softdevice was disabled before going into reset, inform bootloader to skip CRC on next boot
    nrf_pwr_mgmt_shutdown(NRF_PWR_MGMT_SHUTDOWN_GOTO_SYSOFF); // go to system off
  }
}

NRF_SDH_STATE_OBSERVER(m_buttonless_dfu_state_obs, 0) = {
    .handler = buttonless_dfu_sdh_state_observer,
};

static void advertising_config_get(ble_adv_modes_config_t *p_config) {
  memset(p_config, 0, sizeof(ble_adv_modes_config_t));

  p_config->ble_adv_fast_enabled = true;
  p_config->ble_adv_fast_interval = APP_ADV_INTERVAL;
  p_config->ble_adv_fast_timeout = APP_ADV_DURATION;
}

static void disconnect(uint16_t conn_handle, void *p_context) {
  UNUSED_PARAMETER(p_context);

  ret_code_t err_code = sd_ble_gap_disconnect(conn_handle, BLE_HCI_REMOTE_USER_TERMINATED_CONNECTION);
  if (err_code != NRF_SUCCESS) {
    NRF_LOG_WARNING("Failed to disconnect connection. Connection handle: %d Error: %d", conn_handle, err_code);
  } else {
    NRF_LOG_DEBUG("Disconnected connection handle %d", conn_handle);
  }
}

// YOUR_JOB: Update this code if you want to do anything given a DFU event (optional).
/**@brief Function for handling dfu events from the Buttonless Secure DFU service
 *
 * @param[in]   event   Event from the Buttonless Secure DFU service.
 */
static void ble_dfu_evt_handler(ble_dfu_buttonless_evt_type_t event) {
  switch (event) {
  case BLE_DFU_EVT_BOOTLOADER_ENTER_PREPARE: {
    NRF_LOG_INFO("Device is preparing to enter bootloader mode.");

    ble_adv_modes_config_t config; // prevent device from advertising on disconnect
    advertising_config_get(&config);
    config.ble_adv_on_disconnect_disabled = true;
    ble_advertising_modes_config_set(&m_advertising, &config);

    // Disconnect all other bonded devices that currently are connected.
    // This is required to receive a service changed indication
    // on bootup after a successful (or aborted) Device Firmware Update.
    uint32_t conn_count = ble_conn_state_for_each_connected(disconnect, NULL);
    NRF_LOG_INFO("Disconnected %d links.", conn_count);
    break;
  }

  case BLE_DFU_EVT_BOOTLOADER_ENTER:
    // YOUR_JOB: Write app-specific unwritten data to FLASH, control finalization of this
    //           by delaying reset by reporting false in app_shutdown_handler
    NRF_LOG_INFO("Device will enter bootloader mode.");
    break;

  case BLE_DFU_EVT_BOOTLOADER_ENTER_FAILED:
    NRF_LOG_ERROR("Request to enter bootloader mode failed asynchroneously.");
    // YOUR_JOB: Take corrective measures to resolve the issue
    //           like callingAPP_ERROR_CHECK to reset the device.
    break;

  case BLE_DFU_EVT_RESPONSE_SEND_ERROR:
    NRF_LOG_ERROR("Request to send a response to client failed.");
    // YOUR_JOB: Take corrective measures to resolve the issue
    //           like callingAPP_ERROR_CHECK to reset the device.
    APP_ERROR_CHECK(false);
    break;

  default:
    NRF_LOG_ERROR("Unknown event from ble_dfu_buttonless.");
    break;
  }
}

/**@brief Function for handling Peer Manager events.
 *
 * @param[in] p_evt  Peer Manager event.
 */
static void pm_evt_handler(pm_evt_t const *p_evt) {
  pm_handler_on_pm_evt(p_evt);
  pm_handler_flash_clean(p_evt);
}

/**@brief Function for starting timers.
 */
static void application_timers_start(void) {
  // YOUR_JOB: Start your timers. below is an example of how to start a timer.
  // uint32_t err_code;
  // err_code = app_timer_start(m_app_timer_id, TIMER_INTERVAL, NULL);
  // APP_ERROR_CHECK(err_code);
}

/**@brief Function for the Peer Manager initialization.
 */
static void peer_manager_init() {
  ble_gap_sec_params_t sec_param;
  ret_code_t err_code;

  err_code = pm_init();
  APP_ERROR_CHECK(err_code);

  memset(&sec_param, 0, sizeof(ble_gap_sec_params_t));

  sec_param.bond = SEC_PARAM_BOND; // security parameters to be used for all security procedures
  sec_param.mitm = SEC_PARAM_MITM;
  sec_param.lesc = SEC_PARAM_LESC;
  sec_param.keypress = SEC_PARAM_KEYPRESS;
  sec_param.io_caps = SEC_PARAM_IO_CAPABILITIES;
  sec_param.oob = SEC_PARAM_OOB;
  sec_param.min_key_size = SEC_PARAM_MIN_KEY_SIZE;
  sec_param.max_key_size = SEC_PARAM_MAX_KEY_SIZE;
  sec_param.kdist_own.enc = 1;
  sec_param.kdist_own.id = 1;
  sec_param.kdist_peer.enc = 1;
  sec_param.kdist_peer.id = 1;

  err_code = pm_sec_params_set(&sec_param);
  APP_ERROR_CHECK(err_code);

  err_code = pm_register(pm_evt_handler);
  APP_ERROR_CHECK(err_code);
}

/** @brief Clear bonding information from persistent storage.
 */
static void delete_bonds(void) {
  ret_code_t err_code;

  NRF_LOG_INFO("Erase bonds!");

  err_code = pm_peers_delete();
  APP_ERROR_CHECK(err_code);
}

/**@brief Function for starting advertising.
 */
static void advertising_start(void) {
  uint32_t err_code = ble_advertising_start(&m_advertising, BLE_ADV_MODE_FAST);
  APP_ERROR_CHECK(err_code);
}

/**@brief Function for handling an event from the Connection Parameters Module.
 *
 * @details This function will be called for all events in the Connection Parameters Module
 *          which are passed to the application.
 *
 * @note All this function does is to disconnect. This could have been done by simply setting
 *       the disconnect_on_fail config parameter, but instead we use the event handler
 *       mechanism to demonstrate its use.
 *
 * @param[in] p_evt  Event received from the Connection Parameters Module.
 */
static void on_conn_params_evt(ble_conn_params_evt_t *p_evt) {
  uint32_t err_code;

  if (p_evt->evt_type == BLE_CONN_PARAMS_EVT_FAILED) {
    err_code = sd_ble_gap_disconnect(m_conn_handle, BLE_HCI_CONN_INTERVAL_UNACCEPTABLE);
    APP_ERROR_CHECK(err_code);
  }
}

/**@brief Function for handling errors from the Connection Parameters module.
 *
 * @param[in] nrf_error  Error code containing information about what went wrong.
 */
static void conn_params_error_handler(uint32_t nrf_error) {
  APP_ERROR_HANDLER(nrf_error);
}

/**@brief Function for initializing the Connection Parameters module.
 */
static void conn_params_init(void) {
  uint32_t err_code;
  ble_conn_params_init_t cp_init;

  memset(&cp_init, 0, sizeof(cp_init));

  cp_init.p_conn_params = NULL;
  cp_init.first_conn_params_update_delay = FIRST_CONN_PARAMS_UPDATE_DELAY;
  cp_init.next_conn_params_update_delay = NEXT_CONN_PARAMS_UPDATE_DELAY;
  cp_init.max_conn_params_update_count = MAX_CONN_PARAMS_UPDATE_COUNT;
  cp_init.start_on_notify_cccd_handle = BLE_GATT_HANDLE_INVALID;
  cp_init.disconnect_on_fail = false;
  cp_init.evt_handler = on_conn_params_evt;
  cp_init.error_handler = conn_params_error_handler;

  err_code = ble_conn_params_init(&cp_init);
  APP_ERROR_CHECK(err_code);
}

/**@brief Function for putting the chip into sleep mode.
 *
 * @note This function will not return.
 */
static void sleep_mode_enter(void) {
  // uint32_t err_code = bsp_indication_set(BSP_INDICATE_IDLE);
  // APP_ERROR_CHECK(err_code);

  // err_code = bsp_btn_ble_sleep_mode_prepare();  // prepare wakeup buttons
  // APP_ERROR_CHECK(err_code);

  ret_code_t err_code = sd_power_system_off(); // go to system-off mode (this function will not return; wakeup will cause a reset)
  APP_ERROR_CHECK(err_code);
}

/**@brief Function for handling advertising events.
 *
 * @details This function will be called for advertising events which are passed to the application.
 *
 * @param[in] ble_adv_evt  Advertising event.
 */
static void on_adv_evt(ble_adv_evt_t ble_adv_evt) {
  uint32_t err_code;

  switch (ble_adv_evt) {
  case BLE_ADV_EVT_FAST:
    // err_code = bsp_indication_set(BSP_INDICATE_ADVERTISING);
    // APP_ERROR_CHECK(err_code);
    break;
  case BLE_ADV_EVT_IDLE:
    sleep_mode_enter();
    break;
  default:
    break;
  }
}

/**@brief Function for handling BLE events.
 *
 * @param[in]   p_ble_evt   Bluetooth stack event.
 * @param[in]   p_context   Unused.
 */
static void ble_evt_handler(ble_evt_t const *p_ble_evt, void *p_context) {
  uint32_t err_code;

  switch (p_ble_evt->header.evt_id) {
  case BLE_GAP_EVT_CONNECTED:
    NRF_LOG_INFO("Connected");
    // err_code = bsp_indication_set(BSP_INDICATE_CONNECTED);
    // APP_ERROR_CHECK(err_code);
    m_conn_handle = p_ble_evt->evt.gap_evt.conn_handle;
    err_code = nrf_ble_qwr_conn_handle_assign(&m_qwr, m_conn_handle);
    APP_ERROR_CHECK(err_code);
    break;

  case BLE_GAP_EVT_DISCONNECTED:
    NRF_LOG_INFO("Disconnected");
    m_conn_handle = BLE_CONN_HANDLE_INVALID;
    break;

  case BLE_GAP_EVT_PHY_UPDATE_REQUEST: {
    NRF_LOG_DEBUG("PHY update request.");
    ble_gap_phys_t const phys =
        {
            .rx_phys = BLE_GAP_PHY_AUTO,
            .tx_phys = BLE_GAP_PHY_AUTO,
        };
    err_code = sd_ble_gap_phy_update(p_ble_evt->evt.gap_evt.conn_handle, &phys);
    APP_ERROR_CHECK(err_code);
  } break;

  case BLE_GAP_EVT_SEC_PARAMS_REQUEST:
    err_code = sd_ble_gap_sec_params_reply(m_conn_handle, BLE_GAP_SEC_STATUS_PAIRING_NOT_SUPP, NULL, NULL); // pairing not supported
    APP_ERROR_CHECK(err_code);
    break;

  case BLE_GATTS_EVT_SYS_ATTR_MISSING:
    err_code = sd_ble_gatts_sys_attr_set(m_conn_handle, NULL, 0, 0); // no system attributes have been stored
    APP_ERROR_CHECK(err_code);
    break;

  case BLE_GATTC_EVT_TIMEOUT:
    err_code = sd_ble_gap_disconnect(p_ble_evt->evt.gattc_evt.conn_handle, BLE_HCI_REMOTE_USER_TERMINATED_CONNECTION); // disconnect on GATT Client timeout event
    APP_ERROR_CHECK(err_code);
    break;

  case BLE_GATTS_EVT_TIMEOUT:
    err_code = sd_ble_gap_disconnect(p_ble_evt->evt.gatts_evt.conn_handle, BLE_HCI_REMOTE_USER_TERMINATED_CONNECTION); // disconnect on GATT Server timeout event
    APP_ERROR_CHECK(err_code);
    break;

  default:
    break; //  no implementation needed
  }
}

/**@brief Function for the SoftDevice initialization.
 *
 * @details This function initializes the SoftDevice and the BLE event interrupt.
 */
static void ble_stack_init(void) {
  ret_code_t err_code;

  // err_code = nrf_sdh_enable_request();
  // APP_ERROR_CHECK(err_code);

  // Configure the BLE stack using the default settings.
  // Fetch the start address of the application RAM.
  uint32_t ram_start = 0;
  err_code = nrf_sdh_ble_default_cfg_set(APP_BLE_CONN_CFG_TAG, &ram_start);
  APP_ERROR_CHECK(err_code);

  err_code = nrf_sdh_ble_enable(&ram_start); // enable BLE stack
  APP_ERROR_CHECK(err_code);

  NRF_SDH_BLE_OBSERVER(m_ble_observer, APP_BLE_OBSERVER_PRIO, ble_evt_handler, NULL); // register a handler for BLE events
}

static void nus_data_handler(ble_nus_evt_t *p_evt) {
  if (p_evt->type == BLE_NUS_EVT_RX_DATA) {
    char S[BLE_NUS_MAX_DATA_LEN] = {0};
    for (int i = 0; i < p_evt->params.rx_data.length; i++) {
      S[i] = p_evt->params.rx_data.p_data[i];
    }

    bluetooth_get_handle(S); // bluetooth
  }
}
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
  int main(void) {
    ret_code_t err_code;

    nrf_gpio_cfg_output(LED);
    nrf_gpio_pin_clear(LED); // instantly lights LED for the case of wake up

    nrf_gpio_cfg_output(LOAD_EN);
    nrf_gpio_pin_set(LOAD_EN); // turns on power for SPI flash operation
    nrf_delay_ms(100);

    log_init();

    NRF_LOG_INFO(" ");
    NRF_LOG_INFO("Starting firmware...");

    timers_init();
    usb_init();        // must be after timers_init // custom add to SDK, see https://devzone.nordicsemi.com/f/nordic-q-a/36654/usbd_msd-disk-initialization-fails-in-usb-unplug-with-sdk15-0
    softdevice_init(); // must be after usb_init
    button_init();
    led_pwm_init();
    adc_init();
    wake_up(); // wakeup handling after going out of sleep, must be after softdevice init
    imu_init();
    baro_init(); // must be before ble_init
    // gps_init();
    ble_init();
    power_management_init();
    miscellaneous_init();

    vario_configure();

    NRF_LOG_INFO("Firmware has been started!");
    NRF_LOG_INFO(" ");

    for (;;) { // enter the main loop
      vario_check();
      usb_check();
      button_check();
      snd_check();
      // gps_check();
      sleep_check();

      idle_state_handle();

      NRF_LOG_FLUSH();
    }
  }

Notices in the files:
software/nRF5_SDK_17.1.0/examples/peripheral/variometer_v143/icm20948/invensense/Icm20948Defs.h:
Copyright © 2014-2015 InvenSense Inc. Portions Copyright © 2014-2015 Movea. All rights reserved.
